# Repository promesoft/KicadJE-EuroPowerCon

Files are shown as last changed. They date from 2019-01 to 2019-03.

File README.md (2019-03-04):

# KicadEuroPowerCon
Powerplane for Eurorack Doepfer connectors

## Status - Rev B board in prototest - Virtual GND fail
### Initial 
| Stage  | Detail | Status |
| --- | --- | --- |
| create material  | sch/pcb | produced Rev B  |
| | gerber | produced and uploaded RevB |
| production  | ordered  | OK |
|  | produced | OK |
|  | delivered | OK |
### Preliminary validation
| Test  | Detail | Status |
| --- | --- | --- |
| Initial Inspection | Visual - Component Mounting | OK |
| Initial Technical Test | +-20V in +9V in | OK |
| | +/-12v out +5V out | OK |
| | LED's | OK |
| Initial Product Test | Powercon burn in with 10pin VCF | OK |
| Initial Product Test | Powercon 16pin |  OK |
| Initial Product Test | Virtual GND | FAIL - see ERRATA - Working after workaround |
| Initial Product Test | 18-24V single ended bypass reg | VCO - OK |
### Secondary validation
| Test  | Detail | Status |
| --- | --- |--- |
| Product Test | Powercon burn in 10pin | VCF ok|
| Product Test | Powercon 16pin | VCO ok|
| Quality | Linear Regulator Noise | |
| Quality | Dual 12v Switched Mode PSU Noise | |
| Quality | Single 30v Switched Mode PSU Linear Regulator Noise | |
| Quality | Single 24v Switched Mode PSU Noise | |
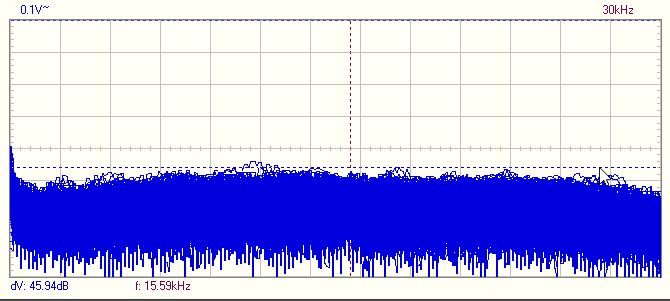
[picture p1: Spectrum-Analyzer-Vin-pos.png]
| | |Input noise | 
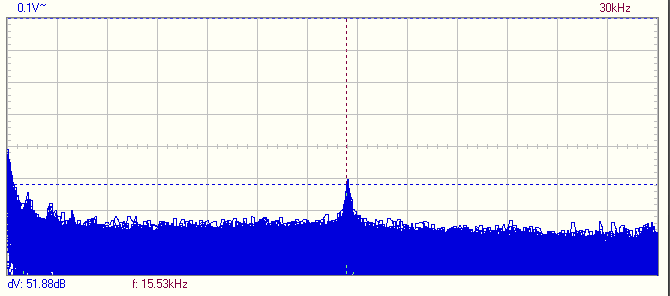
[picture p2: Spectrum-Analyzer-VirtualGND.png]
| | |GND noise |  
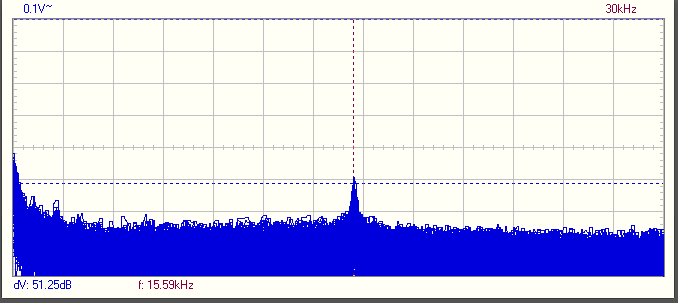
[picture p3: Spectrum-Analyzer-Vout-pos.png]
| | |Output Noise (no 7812/7912 reg - 0R5 resistor replaced common mode filter) | 
| Long Term Product Test | | ongoing |

### Errata
 * Q2 BD140 err in schematic - C and E flipped by mistake
 * Q2 Pin 1 and R11 connected to GND by mistake.
 
### Issues and Notes
 * fuse holder for +5V should be changed
 * virtual GND should be powered behind fuse
 * Q2 becomes warm due to higher load on the positive supply when using Virtual GND on single ended supply.
 
## Physical Construction
100x100mm
Optional cut in 2 where the top part can be used as a normal regulator board.

## Features
+/- 12V Supply
 - Requires +-14,5v to +-27v. Input can be either linear transformer with/without bridge rectifier, or switched mode. 
 - Max 1,5A will require additional cooling of the regulators and larger diodes.
 - Optional disable regulation
 - Optional synthetic GND if only single ended supply is available.
 
+5V Supply
 - Requires 7-25V input either as linear transformer with/without bridge rectifier, or switched mode PSU.
 - Optional input from +15V thru supply 
 - Max 1,5A will require additional cooling of the regulators and larger diodes.
 - Optional disable regulation

Thru
 - Both 7V and +-15 input sections can be sent thru to a second module for daisy chaining of modules.

Reg out
 - Regulated outputs can be send out to other power distribution modules or directly to Synth modules that does not require the Doepfer 10pin or 16pin power input.
 
## Board Layout
- Top - Power in
- Top Right - Regulated power out
- Bottom - Doepfer Powercon

# Electrical Construction
Intended function

## Schematic
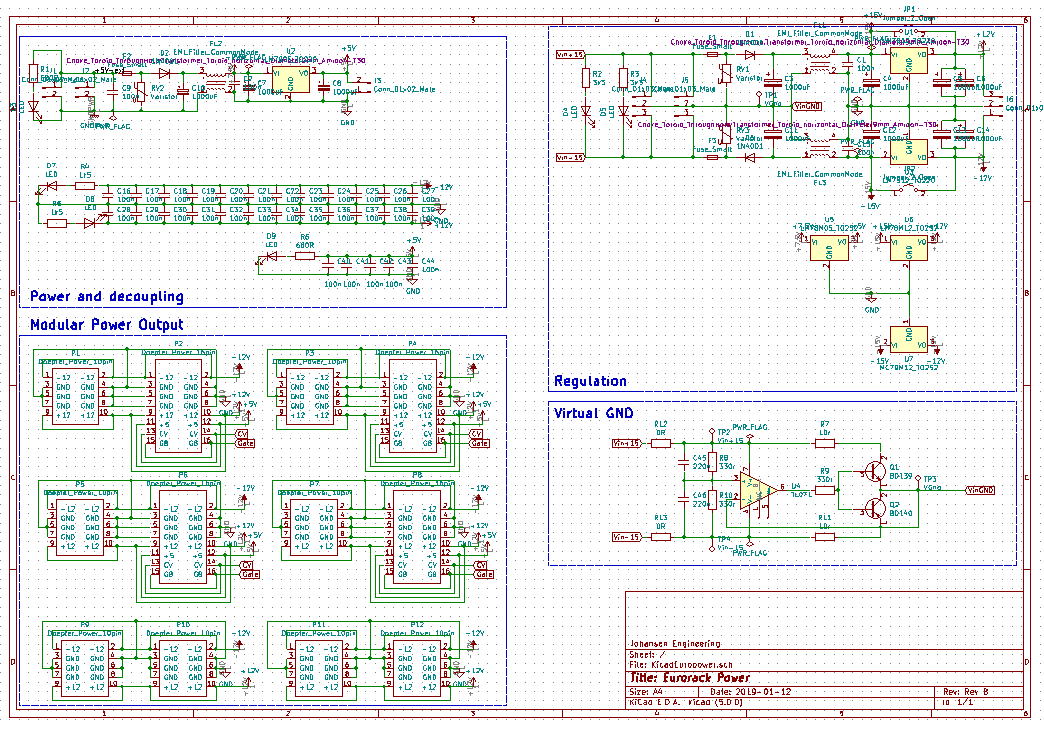
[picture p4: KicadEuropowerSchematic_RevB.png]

## 3D
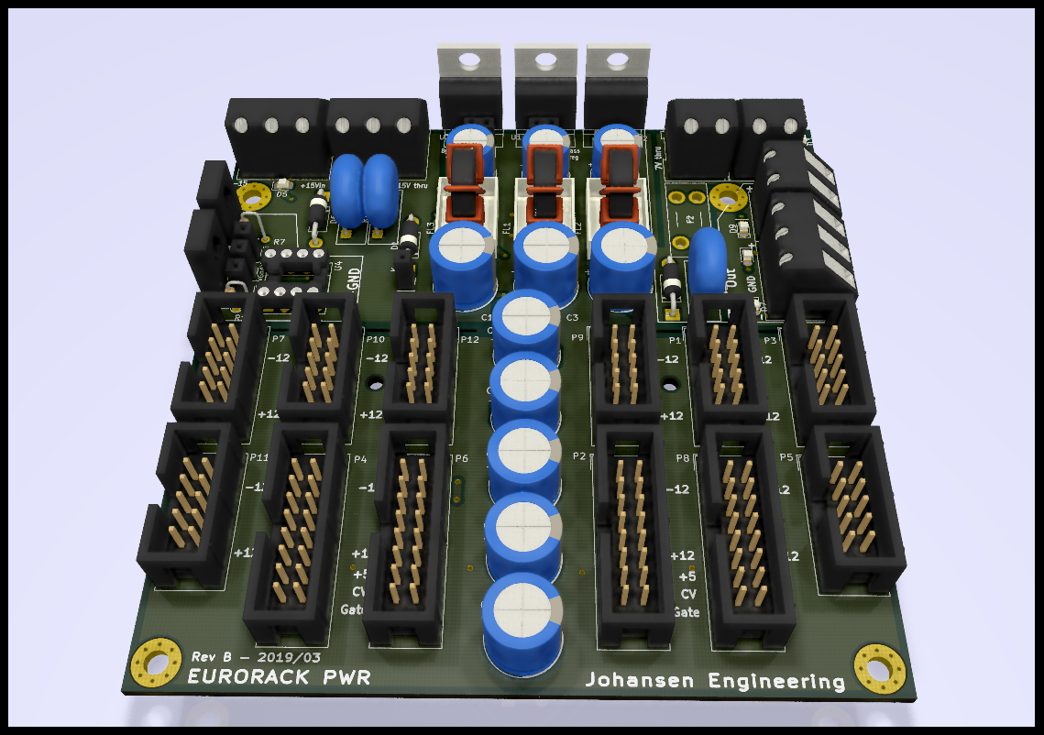
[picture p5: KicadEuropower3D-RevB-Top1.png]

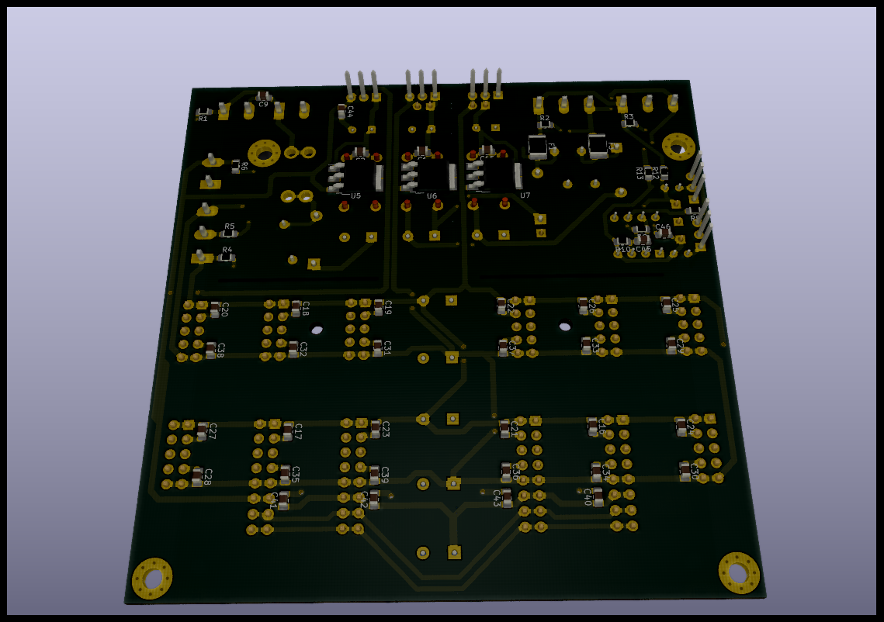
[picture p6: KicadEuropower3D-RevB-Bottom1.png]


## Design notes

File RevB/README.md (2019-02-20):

# KicadEuroPowerCon
Powerplane for Eurorack Doepfer connectors

## Status - Rev B board in prototest - no issues
### Initial 
| Stage  | Detail | Status |
| --- | --- | --- |
| create material  | sch/pcb | produced Rev B  |
| | gerber | produced and uploaded RevB |
| production  | ordered  | OK |
|  | produced | OK |
|  | delivered | OK |
### Preliminary validation
| Test  | Detail | Status |
| --- | --- | --- |
| Initial Inspection | Visual - Component Mounting | OK |
| Initial Technical Test | +-20V in +9V in | OK |
| | +/-12v out +5V out | OK |
| | LED's | OK |
| Initial Product Test | Powercon burn in with 10pin VCF | OK |
| Initial Product Test | Powercon 16pin | |
| Initial Product Test | Virtual GND | |
### Secondary validation
| Test  | Detail | Status |
| --- | --- |--- |
| Product Test | Powercon burn in 10pin | VCF ok|
| Product Test | Powercon 16pin | |
| Quality | Linear Regulator Noise | |
| Quality | Dual 12v Switched Mode PSU Noise | |
| Quality | Single 30v Switched Mode PSU Linear Regulator Noise | |
| Quality | Single 24v Switched Mode PSU Noise | |
| Long Term Product Test | | ongoing |

### Errata

### Issues and Notes
 * fuse holder for +5V should be changed
 * virtual GND should be powered behind fuse
 
## Physical Construction
100x100mm
Optional cut in 2 where the top part can be used as a normal regulator board.

## Features
+/- 12V Supply
 - Requires +-14,5v to +-27v. Input can be either linear transformer with/without bridge rectifier, or switched mode. 
 - Max 1,5A will require additional cooling of the regulators and larger diodes.
 - Optional disable regulation
 - Optional synthetic GND if only single ended supply is available.
 
+5V Supply
 - Requires 7-25V input either as linear transformer with/without bridge rectifier, or switched mode PSU.
 - Optional input from +15V thru supply 
 - Max 1,5A will require additional cooling of the regulators and larger diodes.
 - Optional disable regulation

Thru
 - Both 7V and +-15 input sections can be sent thru to a second module for daisy chaining of modules.

Reg out
 - Regulated outputs can be send out to other power distribution modules or directly to Synth modules that does not require the Doepfer 10pin or 16pin power input.
 
## Board Layout
- Top - Power in
- Top Right - Regulated power out
- Bottom - Doepfer Powercon

# Electrical Construction
Intended function

## Schematic

## 3D



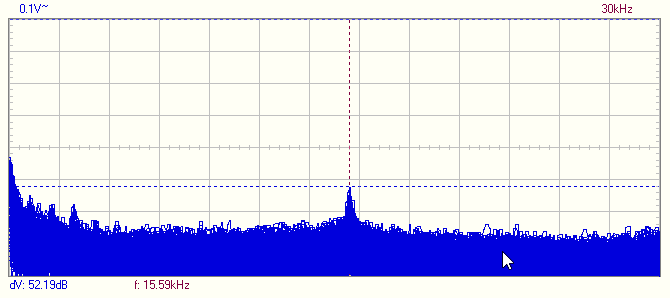
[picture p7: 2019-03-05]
2019-03-04 20_37_25-Spectrum Analyzer.png

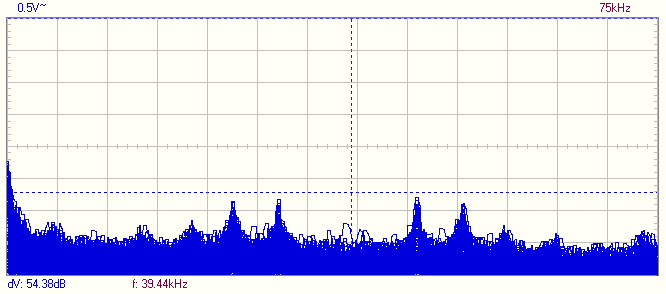
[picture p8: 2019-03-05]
2019-03-04 20_45_35-Spectrum Analyzer.png

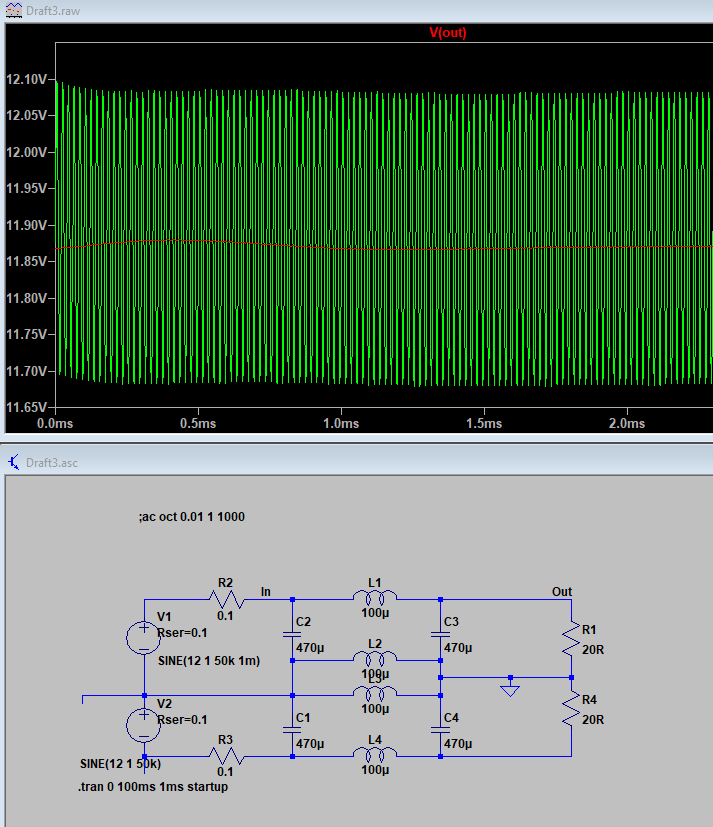
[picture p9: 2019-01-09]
RevB/common_mode_choke_analysis.png

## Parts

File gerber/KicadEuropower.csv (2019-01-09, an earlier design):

Id | Designator | Package | Quantity | Designation | Supplier and ref
1 | REF**,REF**,REF**,REF** | MountingHole_3.2mm_M3_Pad_Via | 4 | MountingHole_3.2mm_M3_Pad_Via
2 | F1,F3 | Fuse_1812_4532Metric_Pad1.30x3.40mm_HandSolder | 2 | Fuse_Small
3 | F2 | Fuseholder_Blade_Mini_Keystone_3568 | 1 | Fuse_Small
4 | P1,P3,P5,P7,P9,P10,P11,P12 | IDC-Header_2x05_Pitch2.54mm_Straight | 8 | Doepfer_Power_10pin
5 | P2,P4,P6,P8 | IDC-Header_2x08_Pitch2.54mm_Straight | 4 | Doepfer_Power_16pin
6 | RV2,RV1,RV3 | RV_Disc_D12mm_W4.8mm_P7.5mm | 3 | Varistor
7 | C1,C2,C15,C16,C17,C18,C19,C20,C21,C22,C23,C24,C25,C26,C27,C28,C29,C30,C31,C32,C33,C34,C35,C36,C37,C38,C39,C40,C41,C42,C43,C44,C9 | C_0805_2012Metric_Pad1.15x1.40mm_HandSolder | 33 | 100n
8 | C4,C7,C12 | CP_Radial_D8.0mm_P3.80mm | 3 | 1000uF
9 | FL1,FL2,FL3 | Transformer_Toroid_horizontal_Diameter9mm_Amidon-T30 | 3 | EMI_Filter_CommonMode
10 | J1,J2,J3 | TerminalBlock_Altech_AK300-2_P5.00mm | 3 | Conn_01x02_Male
11 | J4,J5,J6 | TerminalBlock_Altech_AK300-3_P5.00mm | 3 | Conn_01x03_Male
12 | U1 | TO-220-3_Vertical | 1 | LM7812_TO220
13 | U2 | TO-220-3_Vertical | 1 | LM7805_TO220
14 | U3 | TO-220-3_Vertical | 1 | LM7912_TO220
15 | D1,D2,D6 | D_DO-41_SOD81_P10.16mm_Horizontal | 3 | 1N4001
16 | D3,D4,D5,D7,D8,D9 | LED_0805_2012Metric_Pad1.15x1.40mm_HandSolder | 6 | LED
17 | R1,R6 | R_0805_2012Metric_Pad1.15x1.40mm_HandSolder | 2 | 680R
18 | R2,R3 | R_0805_2012Metric_Pad1.15x1.40mm_HandSolder | 2 | 3k3
19 | R4,R5 | R_0805_2012Metric_Pad1.15x1.40mm_HandSolder | 2 | 1k5
20 | C3,C10,C5,C6,C8,C11,C13,C14 | CP_Radial_D10.0mm_P5.00mm | 8 | 1000uF
21 | Q1 | TO-126-3_Vertical | 1 | BD139
22 | Q2 | TO-126-3_Vertical | 1 | BD140
23 | R7,R11 | R_Axial_DIN0204_L3.6mm_D1.6mm_P2.54mm_Vertical | 2 | 10r
24 | R8,R9,R10 | R_0805_2012Metric_Pad1.15x1.40mm_HandSolder | 3 | 330r
25 | U4 | DIP-8_W7.62mm_Socket | 1 | TL071
26 | C45,C46 | C_0805_2012Metric_Pad1.15x1.40mm_HandSolder | 2 | 220n
27 | TP1,TP3 | PinSocket_1x01_P2.54mm_Vertical | 2 | VGnd
28 | TP2 | PinSocket_1x01_P2.54mm_Vertical | 1 | Vin+15
29 | TP4 | PinSocket_1x01_P2.54mm_Vertical | 1 | Vin-15
30 | JP1,JP2 | PinSocket_1x02_P2.54mm_Vertical | 2 | Jumper_2_Open
31 | R12,R13 | R_0805_2012Metric_Pad1.15x1.40mm_HandSolder | 2 | 0R

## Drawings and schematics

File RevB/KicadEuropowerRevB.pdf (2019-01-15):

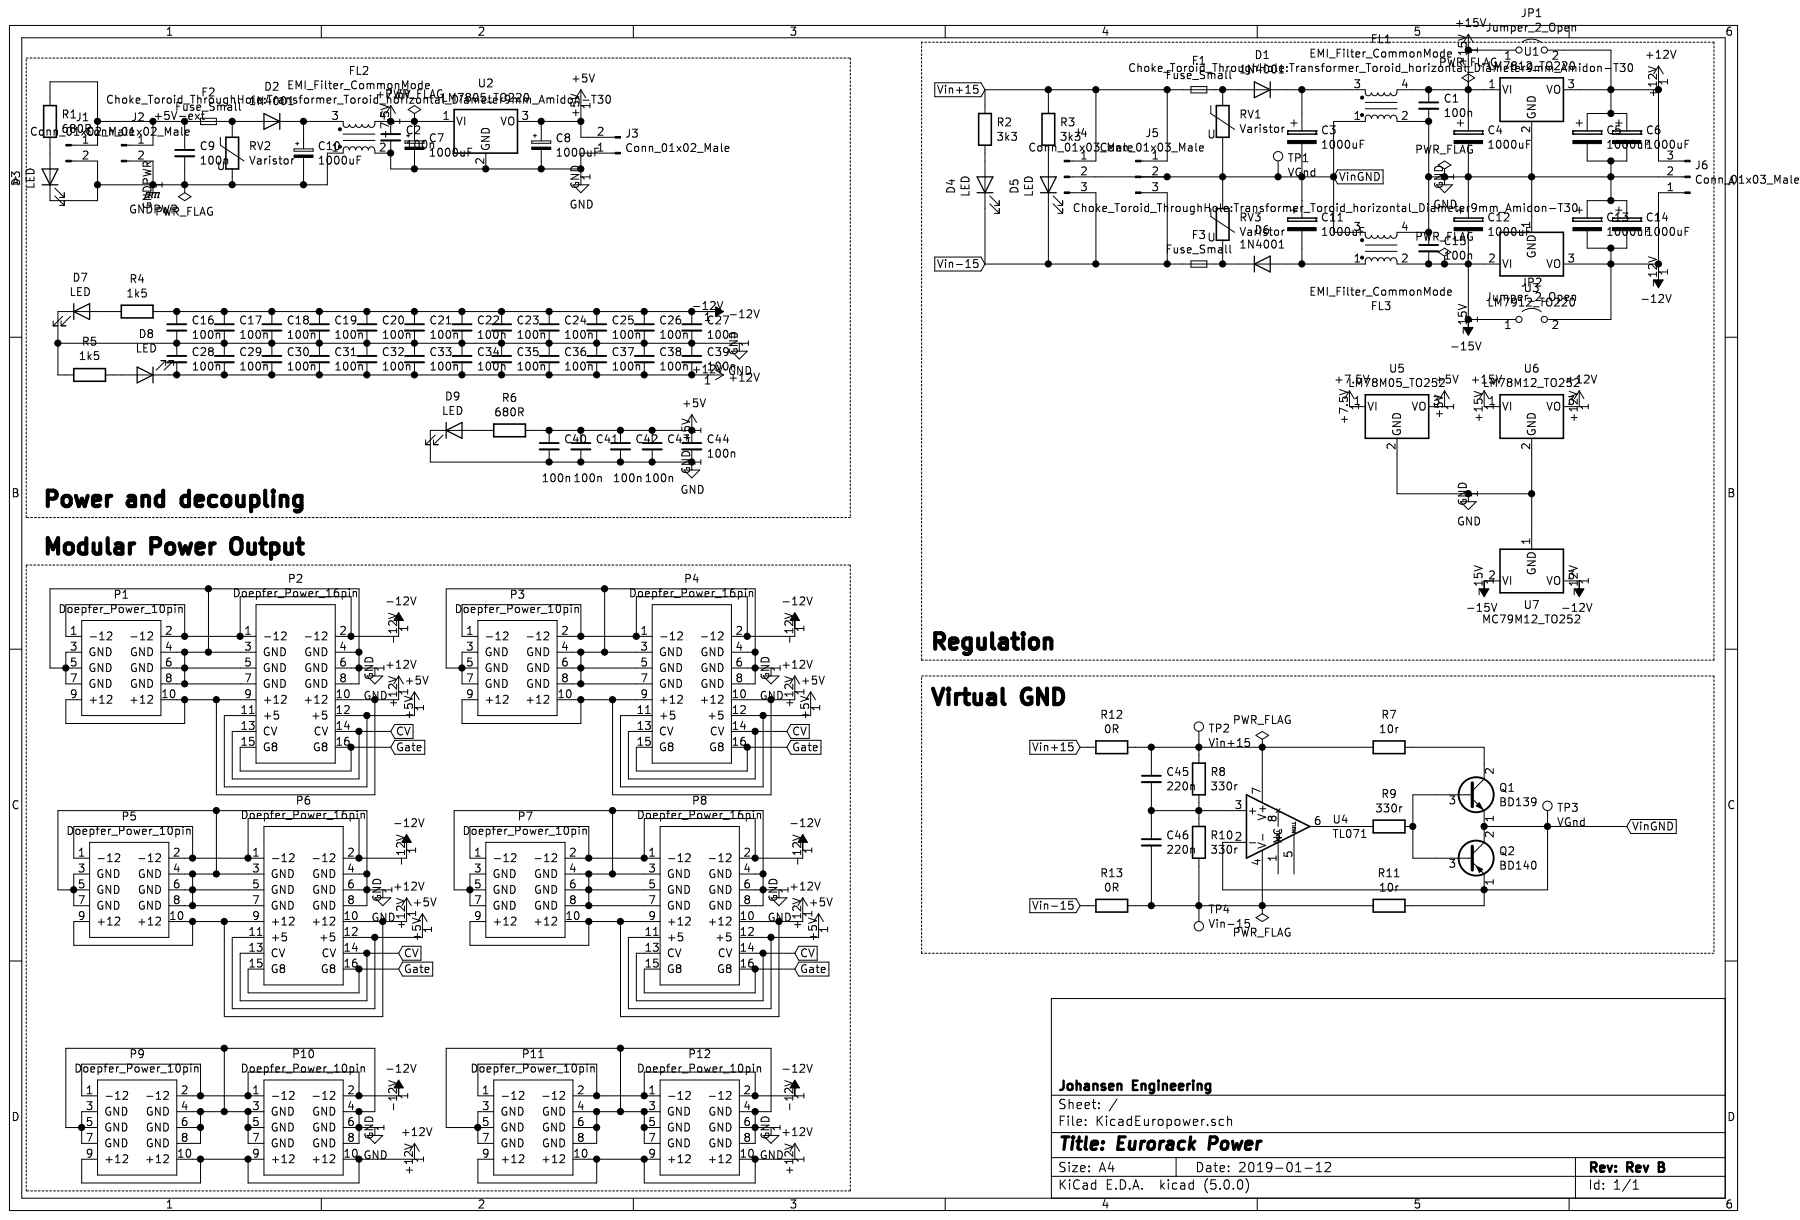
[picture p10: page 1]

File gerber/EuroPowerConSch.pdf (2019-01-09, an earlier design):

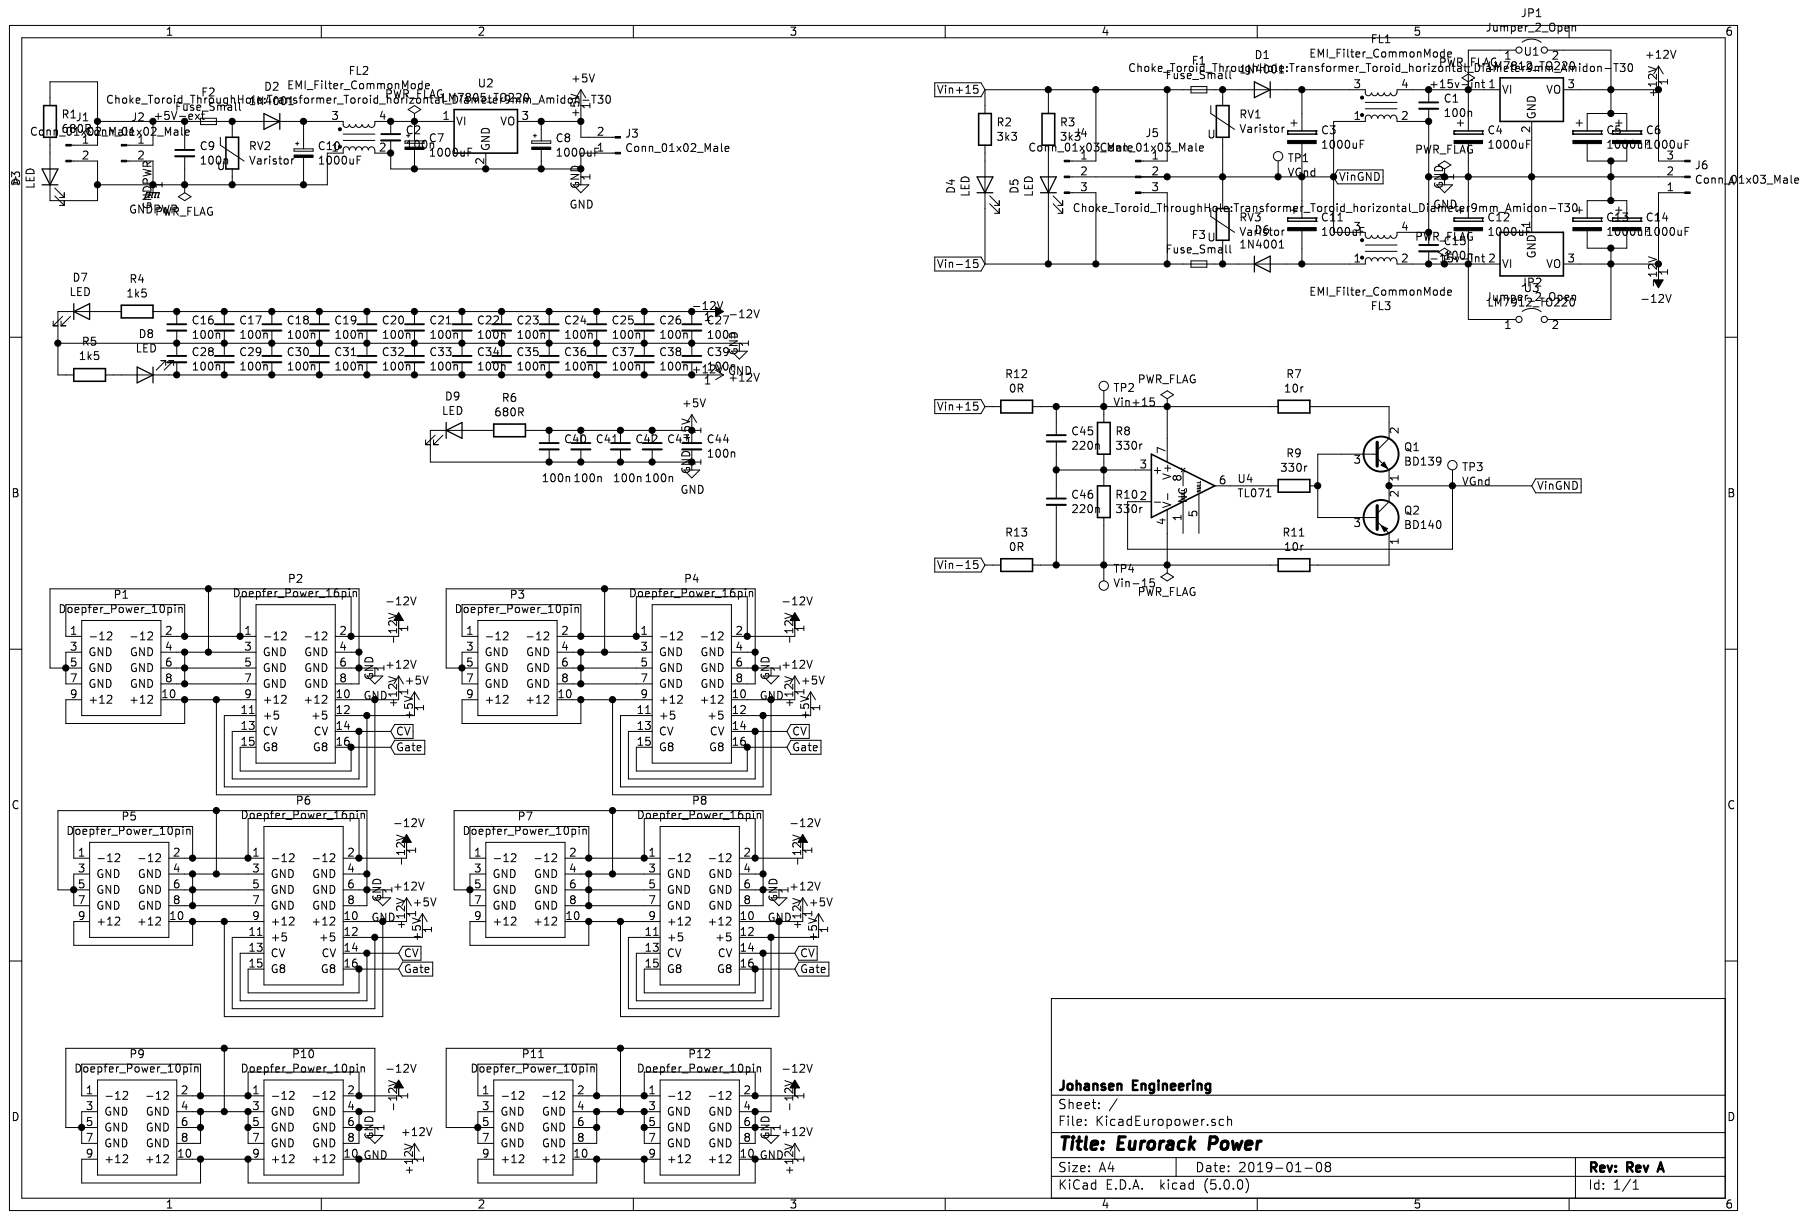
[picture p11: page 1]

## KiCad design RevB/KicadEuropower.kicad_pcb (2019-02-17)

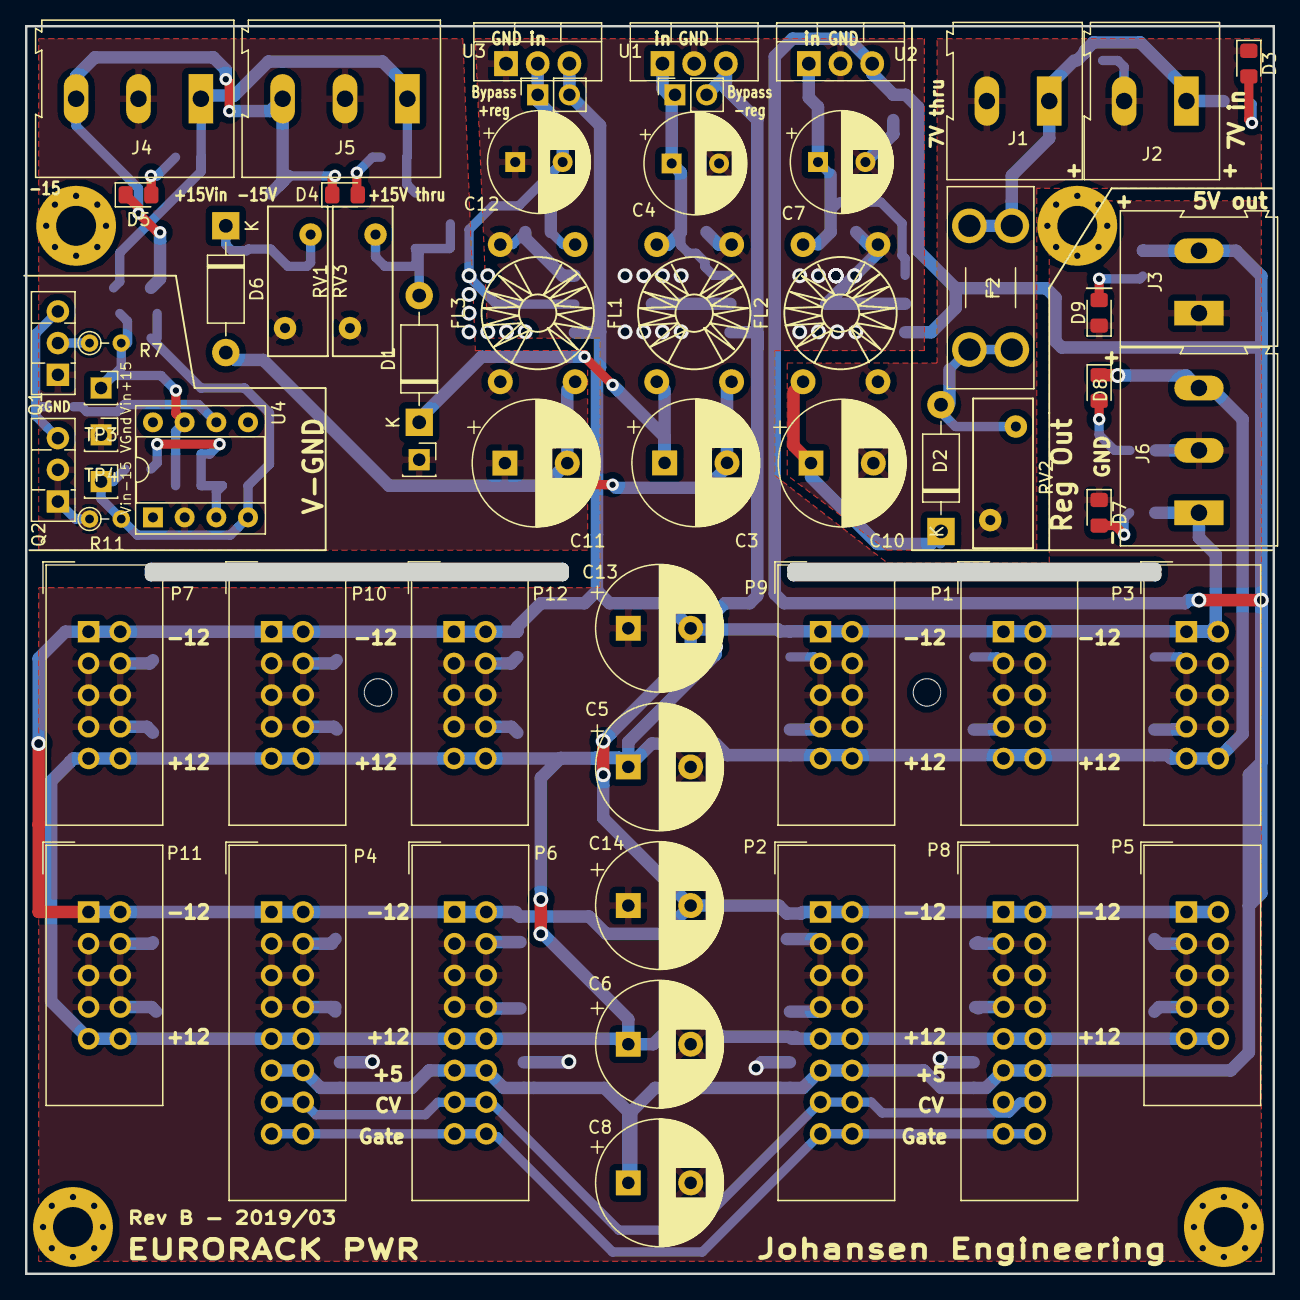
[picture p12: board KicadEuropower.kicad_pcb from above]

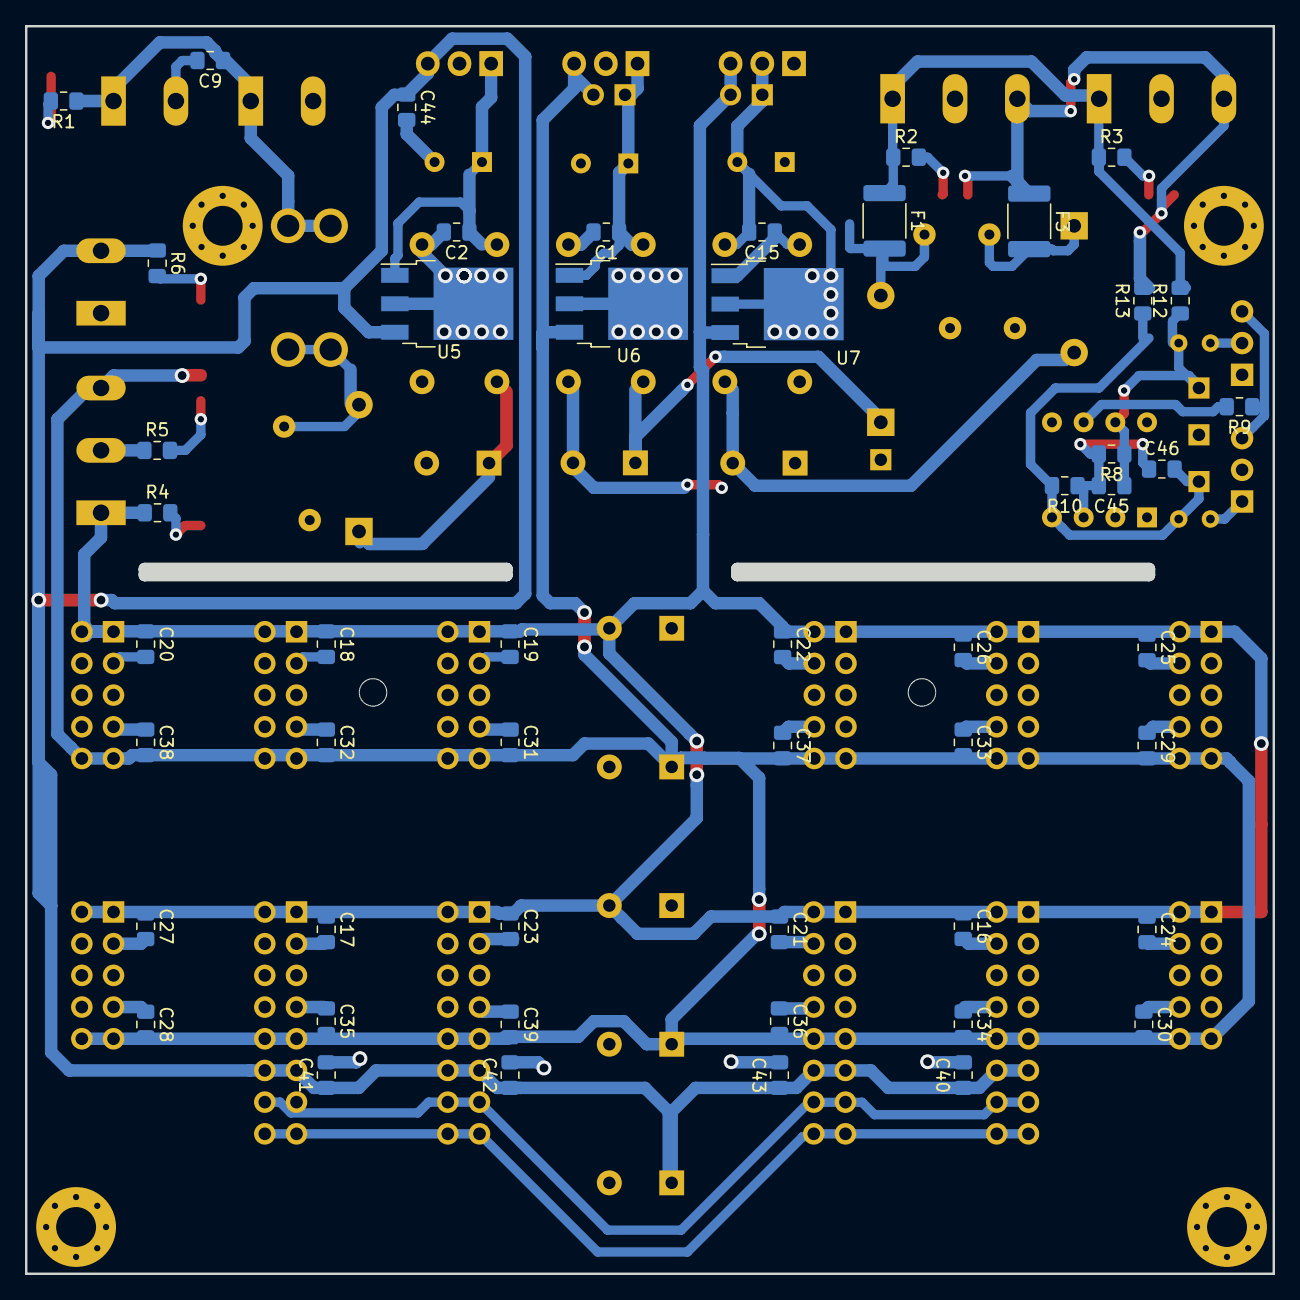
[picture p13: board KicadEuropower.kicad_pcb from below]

Board: 2 copper layers, 100.0 x 100.0 mm, 110 parts (51 on the bottom side), 32 nets.

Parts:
C1, C2, C9, C15, C16, C17, C18, C19, C20, C21, C22, C23, C24, C25, C26, C27, C28, C29, C30, C31, C32, C33, C34, C35, C36, C37, C38, C39, C40, C41, C42, C43, C44: 100n; C_0805_2012Metric_Pad1.15x1.40mm_HandSolder
C3, C5, C6, C8, C10, C11, C13, C14: 1000uF; CP_Radial_D10.0mm_P5.00mm
C4, C7, C12: 1000uF; CP_Radial_D8.0mm_P3.80mm
C45, C46: 220n; C_0805_2012Metric_Pad1.15x1.40mm_HandSolder
D1, D2, D6: 1N4001; D_DO-41_SOD81_P10.16mm_Horizontal
D3, D4, D5, D7, D8, D9: LED; LED_0805_2012Metric_Pad1.15x1.40mm_HandSolder
F1, F3: Fuse_Small; Fuse_1812_4532Metric_Pad1.30x3.40mm_HandSolder
F2: Fuse_Small; Fuseholder_Blade_Mini_Keystone_3568
FL1, FL2, FL3: EMI_Filter_CommonMode; Transformer_Toroid_horizontal_Diameter9mm_Amidon-T30
J1, J2, J3: Conn_01x02_Male; TerminalBlock_Altech_AK300-2_P5.00mm
J4, J5, J6: Conn_01x03_Male; TerminalBlock_Altech_AK300-3_P5.00mm
JP1, JP2: Jumper_2_Open; PinSocket_1x02_P2.54mm_Vertical
P1, P3, P5, P7, P9, P10, P11, P12: Doepfer_Power_10pin; IDC-Header_2x05_Pitch2.54mm_Straight
P2, P4, P6, P8: Doepfer_Power_16pin; IDC-Header_2x08_Pitch2.54mm_Straight
Q1: BD139; TO-126-3_Vertical
Q2: BD140; TO-126-3_Vertical
R1, R6: 680R; R_0805_2012Metric_Pad1.15x1.40mm_HandSolder
R2, R3: 3k3; R_0805_2012Metric_Pad1.15x1.40mm_HandSolder
R4, R5: 1k5; R_0805_2012Metric_Pad1.15x1.40mm_HandSolder
R7, R11: 10r; R_Axial_DIN0204_L3.6mm_D1.6mm_P2.54mm_Vertical
R8, R9, R10: 330r; R_0805_2012Metric_Pad1.15x1.40mm_HandSolder
R12, R13: 0R; R_0805_2012Metric_Pad1.15x1.40mm_HandSolder
RV1, RV2, RV3: Varistor; RV_Disc_D12mm_W4.8mm_P7.5mm
TP1, TP3: VGnd; PinSocket_1x01_P2.54mm_Vertical
TP2: Vin+15; PinSocket_1x01_P2.54mm_Vertical
TP4: Vin-15; PinSocket_1x01_P2.54mm_Vertical
U1: LM7812_TO220; TO-220-3_Vertical
U2: LM7805_TO220; TO-220-3_Vertical
U3: LM7912_TO220; TO-220-3_Vertical
U4: TL071; DIP-8_W7.62mm_Socket
U5: LM78M05_TO252; TO-252-3_TabPin2
U6: LM78M12_TO252; TO-252-3_TabPin2
U7: MC79M12_TO252; TO-252-3_TabPin2

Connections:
+5V: C8.1, C40.1, C41.1, C42.1, C43.1, C44.1, J3.2, P2.11, P2.12, P4.11, P4.12, P6.11, P6.12, P8.11, P8.12, R6.1, U2.3, U5.3
+7.5V: C2.1, C7.1, FL2.4, U2.1, U5.1
+12V: C5.1, C6.1, C28.2, C29.2, C30.2, C31.2, C32.2, C33.2, C34.2, C35.2, C36.2, C37.2, C38.2, C39.2, D8.1, J6.3, JP1.2, P1.9, P1.10, P2.9, P2.10, P3.9, P3.10, P4.9, P4.10, P5.9, P5.10, P6.9, P6.10, P7.9, P7.10, P8.9, P8.10, P9.9, P9.10, P10.9, P10.10, P11.9, P11.10, P12.9, P12.10, U1.3, U6.3
+15V: C1.1, C4.1, FL1.4, JP1.1, U1.1, U6.1
-12V: C13.2, C14.2, C16.1, C17.1, C18.1, C19.1, C20.1, C21.1, C22.1, C23.1, C24.1, C25.1, C26.1, C27.1, J6.1, JP2.2, P1.1, P1.2, P2.1, P2.2, P3.1, P3.2, P4.1, P4.2, P5.1, P5.2, P6.1, P6.2, P7.1, P7.2, P8.1, P8.2, P9.1, P9.2, P10.1, P10.2, P11.1, P11.2, P12.1, P12.2, R4.1, U3.3, U7.3
-15V: C12.2, C15.2, FL3.2, JP2.1, U3.2, U7.2
/+5V-ext: C9.1, F2.1, J1.1, J2.1, R1.1
CV: P2.13, P2.14, P4.13, P4.14, P6.13, P6.14, P8.13, P8.14
GND: C1.2, C2.2, C4.2, C5.2, C6.2, C7.2, C8.2, C12.1, C13.1, C14.1, C15.1, C16.2, C17.2, C18.2, C19.2, C20.2, C21.2, C22.2, C23.2, C24.2, C25.2, C26.2, C27.2, C28.1, C29.1, C30.1, C31.1, C32.1, C33.1, C34.1, C35.1, C36.1, C37.1, C38.1, C39.1, C40.2, C41.2, C42.2, C43.2, C44.2, D7.1, D9.1, FL1.2, FL2.2, FL3.4, J3.1, J6.2, P1.3, P1.4, P1.5, P1.6, P1.7, P1.8, P2.3, P2.4, P2.5, P2.6, P2.7, P2.8, P3.3, P3.4, P3.5, P3.6, P3.7, P3.8, P4.3, P4.4, P4.5, P4.6, P4.7, P4.8, P5.3, P5.4, P5.5, P5.6, P5.7, P5.8, P6.3, P6.4, P6.5, P6.6, P6.7, P6.8, P7.3, P7.4, P7.5, P7.6, P7.7, P7.8, P8.3, P8.4, P8.5, P8.6, P8.7, P8.8, P9.3, P9.4, P9.5, P9.6, P9.7, P9.8, P10.3, P10.4, P10.5, P10.6, P10.7, P10.8, P11.3, P11.4, P11.5, P11.6, P11.7, P11.8, P12.3, P12.4, P12.5, P12.6, P12.7, P12.8, R5.1, U1.2, U2.2, U3.1, U5.2, U6.2, U7.1
GNDPWR: C9.2, C10.2, D3.1, FL2.1, J1.2, J2.2, RV2.2
Gate: P2.15, P2.16, P4.15, P4.16, P6.15, P6.16, P8.15, P8.16
unnamed: C3.1, D1.1, FL1.3
unnamed: C10.1, D2.1, FL2.3
unnamed: C11.2, D6.2, FL3.1
unnamed: C45.1, R7.2, R8.1, R12.1, TP2.1, U4.7
unnamed: C45.2, C46.1, R8.2, R10.1, U4.3
unnamed: C46.2, R10.2, R11.2, R13.1, TP4.1, U4.4
unnamed: D1.2, F1.2, RV1.1
unnamed: D2.2, F2.2, RV2.1
unnamed: D3.2, R1.2
unnamed: D4.2, R2.2
unnamed: D5.2, R3.2
unnamed: D6.1, F3.2, RV3.2
unnamed: D7.2, R4.2
unnamed: D8.2, R5.2
unnamed: D9.2, R6.2
unnamed: Q1.2, R7.1
unnamed: Q1.3, Q2.3, R9.1
unnamed: R9.2, U4.6
Vin+15: F1.1, J4.1, J5.1, R2.1, R3.1, R12.2
Vin-15: D4.1, D5.1, F3.1, J4.3, J5.3, R13.2
VinGND: C3.2, C11.1, FL1.1, FL3.3, J4.2, J5.2, Q1.1, Q2.1, Q2.2, R11.1, RV1.2, RV3.1, TP1.1, TP3.1, U4.2

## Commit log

2019-01-07 Getting started
    [KicadEuropower.kicad_pcb, KicadEuropower.sch]
2019-01-07 +5V +/-12 sch
    [KicadEuropower.sch]
2019-01-07 PCB Placement started
    [KicadEuropower.kicad_pcb, _saved_KicadEuropower.sch]
2019-01-08 3D shapes init
    [KicadEuropower.kicad_pcb, _saved_KicadEuropower.sch]
2019-01-08 Footprint updates
    [KicadEuropower.sch, _saved_KicadEuropower.sch]
2019-01-08 Power upd and 2x10pin removed
2019-01-08 Component placement update
    [KicadEuropower.kicad_pcb, KicadEuropower.sch]
2019-01-08 Virtual GND
    [KicadEuropower.sch]
2019-01-08 Mounting holes and Text
    [KicadEuropower.kicad_pcb]
2019-01-08 Groundplanes placed
    [KicadEuropower.csv, KicadEuropower.kicad_pcb, _saved_KicadEuropower.sch]
2019-01-08 Rev A - Mechanical + Component placement + Text
    [KicadEuropower.kicad_pcb, _saved_KicadEuropower.sch]
2019-01-08 Fixed missing +12V on several connectors
    [KicadEuropower.sch, _saved_KicadEuropower.sch]
2019-01-08 Added SMD 0R to Virtual GND pwr feed
    [KicadEuropower.sch]
2019-01-08 Cleared zones around mounting holes - 3D rendered img
2019-01-09 Minor Update to PCB - New Gerber
    [KicadEuropower-B.Cu.gbr, KicadEuropower-B.Mask.gbr, KicadEuropower-B.Paste.gbr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]
2019-01-12 Optional TO252 regulators and added mounting holes
    [KicadEuropower.kicad_pcb, _saved_KicadEuropower.sch]
2019-01-14 Extra reg
    [KicadEuropower.sch, _saved_KicadEuropower.sch]
2019-01-15 Rev B Gerber
    Gerber export
    Schematic Update (visual)
    Cleanup of Rev A
    [KicadEuropower-B.Cu.gbr, KicadEuropower-B.Mask.gbr, KicadEuropower-B.Paste.gbr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]
2019-02-21 Rev C prepare
    [KicadEuropower.kicad_pcb, KicadEuropower.sch]
2019-02-21 Diode bridge replacing diodes in +-12v - VGND gets fused pwr - +5V on 1812 fuse
    [KicadEuropower.sch]
2019-02-21 fuses +5V and +-12 changed to 1210
    [KicadEuropower.sch]
2019-03-03 SCH fixed VGND err
    [KicadEuropower.sch]
